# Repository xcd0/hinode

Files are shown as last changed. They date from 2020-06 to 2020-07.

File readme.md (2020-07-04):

# hinode

手配線で作る自作キーボードです。  
ケースは3Dプリンターで作りました。



  

3DモデルはFusion360で作成しています。  
元のファイルも公開してよいのですが、ちまちま修正が続いており、  
かつAutodeskのクラウド上に保存され、gitと同期が難しいため置いていません。  
あまりきれいなモデルではないですが、元のファイルが欲しい方は言ってください。  
[需要あるかわかりませんがstlファイルも置いています。](./hinode.stl)

回路図です。といっても手配線ですので目安です。  


ファームウェアはhelixのものを編集して使っています。

## キーボードレイアウト

レイヤー名をクリックすると[http://www.keyboard-layout-editor.com/](http://www.keyboard-layout-editor.com/)でふわっと作ったページに飛ぶことができます。  
レイヤーは6つあります。後ろ3つはほぼスッカスカです。  

| レイヤー番号 | 名前 | 簡単な説明 |
| :---: | :---: | --- |
| 1 | [Qwerty](http://www.keyboard-layout-editor.com/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<&_x:4%3B&=>&=6%0A%0A%0A%0AF6&=7%0A%0A%0A%0AF7&=8%0A%0A%0A%0AF8&=9%0A%0A%0A%0AF9&=0%0A%0A%0A%0AF10&=-%0A%0A%0A%0AF11&=Del%0A%0A%0A%0AF12%3B&@_c=%23f7c199%3B&=GUI&_c=%23cccccc%3B&=Tab&=Q&=W&=E&=R&=T&=(&_x:4%3B&=)&=Y&=U&=I&=O&=P&=%2F@&=Bs%3B&@_c=%23f7c199%3B&=Ins&_c=%23d18686%3B&=Sym&_c=%23cccccc%3B&=A&=S&=D&=F&=G%0A%0A%0A%0AQWERTY&=%5B%0A%0A%0A%0AEE%20RST&_x:4%3B&=%5D&=H&=J&=K&=L&=%2F%3B&=%2F:&=Ent%3B&@_c=%23f7c199%3B&=Home&=&_c=%23cccccc%3B&=Z&=X&=C&=V&=B%0A%0A%0A%0AYSTRP&=%7B%0A%0A%0A%0ARST&_x:4%3B&=%7D&=N&=M&=,&=.&=%2F%2F&=%5C&_c=%23f7c199%3B&=End%3B&@_rx:5.1&ry:9.55&y:-5.550000000000001&x:-0.5999999999999996&c=%23cccccc%3B&=英%3B&@_rx:15.1&ry:8.7&y:-4.699999999999999&x:-0.5999999999999996&c=%23f7c199%3B&=かな%3B&@_r:15&rx:5.1&y:-4.699999999999999&x:-0.5999999999999996%3B&=Ctlr%3B&@_r:30&y:-1&x:-0.5999999999999996%3B&=Shift%3B&@_r:45&y:-1&x:-0.5999999999999996%3B&=Spc%3B&@_r:60&y:-1&x:-0.5999999999999996&c=%23d18686%3B&=←%3B&@_r:-60&rx:15.1&y:-4.699999999999999&x:-0.5999999999999996%3B&=→%3B&@_r:-45&y:-1&x:-0.5999999999999996&c=%23f7c199%3B&=Bs%3B&@_r:-30&y:-1&x:-0.5999999999999996%3B&=Ent%3B&@_r:-15&y:-1&x:-0.5999999999999996%3B&=Del) | デフォルトのレイヤーです |
| 2 | [Ystrp](http://www.keyboard-layout-editor.com/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<&_x:4%3B&=>&=6%0A%0A%0A%0AF6&=7%0A%0A%0A%0AF7&=8%0A%0A%0A%0AF8&=9%0A%0A%0A%0AF9&=0%0A%0A%0A%0AF10&=-%0A%0A%0A%0AF11&=Del%0A%0A%0A%0AF12%3B&@_c=%23f7c199%3B&=GUI&_c=%23cccccc%3B&=Tab&=Q&=W&_c=%23a7a9fc%3B&=D&=F&=G&_c=%23cccccc%3B&=(&_x:4%3B&=)&=Y&_c=%23a7a9fc%3B&=S&=T&=R&_c=%23cccccc%3B&=P&=%2F@&=Bs%3B&@_c=%23f7c199%3B&=Ins&_c=%23d18686%3B&=Sym&_c=%23cccccc%3B&=A&_c=%23a7a9fc%3B&=O&=E&=U&=I%0A%0A%0A%0AQWERTY&_c=%23cccccc%3B&=%5B%0A%0A%0A%0AEE%20RST&_x:4%3B&=%5D&=H&=J&=K&=L&=%2F%3B&=%2F:&=Ent%3B&@_c=%23f7c199%3B&=Home&=&_c=%23cccccc%3B&=Z&=X&=C&=V&=B%0A%0A%0A%0AYSTRP&=%7B%0A%0A%0A%0ARST&_x:4%3B&=%7D&=N&=M&=,&=.&=%2F%2F&=%5C&_c=%23f7c199%3B&=End%3B&@_rx:5.1&ry:9.55&y:-5.550000000000001&x:-0.5999999999999996&c=%23cccccc%3B&=英%3B&@_rx:15.1&ry:8.7&y:-4.699999999999999&x:-0.5999999999999996&c=%23f7c199%3B&=かな%3B&@_r:15&rx:5.1&y:-4.699999999999999&x:-0.5999999999999996%3B&=Ctlr%3B&@_r:30&y:-1&x:-0.5999999999999996%3B&=Shift%3B&@_r:45&y:-1&x:-0.5999999999999996%3B&=Spc%3B&@_r:60&y:-1&x:-0.5999999999999996&c=%23d18686%3B&=←%3B&@_r:-60&rx:15.1&y:-4.699999999999999&x:-0.5999999999999996%3B&=→%3B&@_r:-45&y:-1&x:-0.5999999999999996&c=%23f7c199%3B&=Bs%3B&@_r:-30&y:-1&x:-0.5999999999999996%3B&=Ent%3B&@_r:-15&y:-1&x:-0.5999999999999996%3B&=Del ) | 独自キー配列のレイヤーです |
| 3 | [Symbol](http://www.keyboard-layout-editor.com/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"&='&=%60&=&_x:4%3B&=&=$&=(&=<&=%7B&=%5B&=&=Bs%3B&@_c=%23f7c199%3B&=Ins&_c=%23d18686%3B&=&_c=%23cccccc%3B&=+&=-&=*&=%2F=&=%2F:&=&_x:4%3B&=&=!&=)&=>&=%7D&=%5D&=&=Ent%3B&@_c=%23f7c199%3B&=Home&=&_c=%23cccccc%3B&=!&=%3F&=%23&=$&=%25&=&_x:4%3B&=&=&=%2F@&=%5E&=,&=&=&_c=%23f7c199%3B&=End%3B&@_rx:5.1&ry:9.55&y:-5.550000000000001&x:-0.5999999999999996&c=%23cccccc%3B&=英%3B&@_rx:15.1&ry:8.7&y:-4.699999999999999&x:-0.5999999999999996&c=%23f7c199%3B&=かな%3B&@_r:15&rx:5.1&y:-4.699999999999999&x:-0.5999999999999996%3B&=Ctlr%3B&@_r:30&y:-1&x:-0.5999999999999996%3B&=Shift%3B&@_r:45&y:-1&x:-0.5999999999999996%3B&=Spc%3B&@_r:60&y:-1&x:-0.5999999999999996&c=%23d18686%3B&=←%3B&@_r:-60&rx:15.1&y:-4.699999999999999&x:-0.5999999999999996%3B&=→%3B&@_r:-45&y:-1&x:-0.5999999999999996&c=%23f7c199%3B&=Bs%3B&@_r:-30&y:-1&x:-0.5999999999999996%3B&=Ent%3B&@_r:-15&y:-1&x:-0.5999999999999996%3B&=Del) | 記号レイヤーです |
| 4 | [Leftside](http://www.keyboard-layout-editor.com/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<br>Reset&_x:4&f:5%3B&=&=←&=↓&=↑&=→&=&=&=%3B&@_c=%23f7c199%3B&=&=&_c=%23cccccc%3B&=&=&=&=&_f:3%3B&=Ystrp&=Reset&_x:4&f:5%3B&=&=&=&=&=&=&=&_c=%23f7c199%3B&=%3B&@_rx:5.1&ry:9.55&y:-5.550000000000001&x:-0.5999999999999996&c=%23cccccc%3B&=%3B&@_rx:15.1&ry:8.7&y:-4.699999999999999&x:-0.5999999999999996&c=%23f7c199%3B&=%3B&@_r:15&rx:5.1&y:-4.699999999999999&x:-0.5999999999999996%3B&=Ctlr%3B&@_r:30&y:-1&x:-0.5999999999999996%3B&=Shift%3B&@_r:45&y:-1&x:-0.5999999999999996%3B&=Spc%3B&@_r:60&y:-1&x:-0.5999999999999996&c=%23d18686%3B&=%3B&@_r:-60&rx:15.1&y:-4.699999999999999&x:-0.5999999999999996&f:3%3B&=Adjust%3B&@_r:-45&y:-1&x:-0.5999999999999996&c=%23f7c199&f:5%3B&=Bs%3B&@_r:-30&y:-1&x:-0.5999999999999996%3B&=Ent%3B&@_r:-15&y:-1&x:-0.5999999999999996%3B&=Del) | 方向キーを置いています |
| 5 | [Rightside](http://www.keyboard-layout-editor.com/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<br>Left<br>Click&_a:5%3B&=Mouse<br>Mid<br>Click&_a:7%3B&=Mouse<br>Right<br>Click&=Mouse<br>Wheel<br>Up&_f:5%3B&=&=%3B&@_c=%23f7c199%3B&=&_c=%23d18686%3B&=&_c=%23cccccc%3B&=&=&=&=&_f:3%3B&=Qwerty&_f:1%3B&=EEPROM<br>Reset&_x:4&f:5%3B&=&_f:3%3B&=Mouse<br>←&=Mouse<br>↓&=Mouse<br>↑&=Mouse<br>→&=Mouse<br>Wheel<br>Down&_f:5%3B&=&=%3B&@_c=%23f7c199%3B&=&=&_c=%23cccccc%3B&=&=&=&=&_f:3%3B&=Ystrp&=Reset&_x:4&f:5%3B&=&=&=&=&=&=&=&_c=%23f7c199%3B&=%3B&@_rx:5.1&ry:9.55&y:-5.550000000000001&x:-0.5999999999999996&c=%23cccccc%3B&=%3B&@_rx:15.1&ry:8.7&y:-4.699999999999999&x:-0.5999999999999996&c=%23f7c199%3B&=%3B&@_r:15&rx:5.1&y:-4.699999999999999&x:-0.5999999999999996%3B&=Ctlr%3B&@_r:30&y:-1&x:-0.5999999999999996%3B&=Shift%3B&@_r:45&y:-1&x:-0.5999999999999996%3B&=Spc%3B&@_r:60&y:-1&x:-0.5999999999999996&c=%23d18686&f:3%3B&=Adjust%3B&@_r:-60&rx:15.1&y:-4.699999999999999&x:-0.5999999999999996&f:5%3B&=%3B&@_r:-45&y:-1&x:-0.5999999999999996&c=%23f7c199%3B&=Bs%3B&@_r:-30&y:-1&x:-0.5999999999999996%3B&=Ent%3B&@_r:-15&y:-1&x:-0.5999999999999996%3B&=Del) | マウスポインタの操作ができます |
| 6 | [Adjust](http://www.keyboard-layout-editor.com/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) | 何も配置していません |

## レイヤー詳細

キーボードにはレイヤーが6つ割り当てられています。  

1. [Qwerty](http://www.keyboard-layout-editor.com/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<&_x:4%3B&=>&=6%0A%0A%0A%0AF6&=7%0A%0A%0A%0AF7&=8%0A%0A%0A%0AF8&=9%0A%0A%0A%0AF9&=0%0A%0A%0A%0AF10&=-%0A%0A%0A%0AF11&=Del%0A%0A%0A%0AF12%3B&@_c=%23f7c199%3B&=GUI&_c=%23cccccc%3B&=Tab&=Q&=W&=E&=R&=T&=(&_x:4%3B&=)&=Y&=U&=I&=O&=P&=%2F@&=Bs%3B&@_c=%23f7c199%3B&=Ins&_c=%23d18686%3B&=Sym&_c=%23cccccc%3B&=A&=S&=D&=F&=G%0A%0A%0A%0AQWERTY&=%5B%0A%0A%0A%0AEE%20RST&_x:4%3B&=%5D&=H&=J&=K&=L&=%2F%3B&=%2F:&=Ent%3B&@_c=%23f7c199%3B&=Home&=&_c=%23cccccc%3B&=Z&=X&=C&=V&=B%0A%0A%0A%0AYSTRP&=%7B%0A%0A%0A%0ARST&_x:4%3B&=%7D&=N&=M&=,&=.&=%2F%2F&=%5C&_c=%23f7c199%3B&=End%3B&@_rx:5.1&ry:9.55&y:-5.550000000000001&x:-0.5999999999999996&c=%23cccccc%3B&=英%3B&@_rx:15.1&ry:8.7&y:-4.699999999999999&x:-0.5999999999999996&c=%23f7c199%3B&=かな%3B&@_r:15&rx:5.1&y:-4.699999999999999&x:-0.5999999999999996%3B&=Ctlr%3B&@_r:30&y:-1&x:-0.5999999999999996%3B&=Shift%3B&@_r:45&y:-1&x:-0.5999999999999996%3B&=Spc%3B&@_r:60&y:-1&x:-0.5999999999999996&c=%23d18686%3B&=←%3B&@_r:-60&rx:15.1&y:-4.699999999999999&x:-0.5999999999999996%3B&=→%3B&@_r:-45&y:-1&x:-0.5999999999999996&c=%23f7c199%3B&=Bs%3B&@_r:-30&y:-1&x:-0.5999999999999996%3B&=Ent%3B&@_r:-15&y:-1&x:-0.5999999999999996%3B&=Del)  
2. [Ystrp](http://www.keyboard-layout-editor.com/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<&_x:4%3B&=>&=6%0A%0A%0A%0AF6&=7%0A%0A%0A%0AF7&=8%0A%0A%0A%0AF8&=9%0A%0A%0A%0AF9&=0%0A%0A%0A%0AF10&=-%0A%0A%0A%0AF11&=Del%0A%0A%0A%0AF12%3B&@_c=%23f7c199%3B&=GUI&_c=%23dedfff%3B&=Tab&_c=%23cccccc%3B&=Q&=W&_c=%23a7a9fc%3B&=D&=F&=G&_c=%23cccccc%3B&=(&_x:4%3B&=)&=Y&_c=%23a7a9fc%3B&=S&=T&=R&_c=%23cccccc%3B&=P&=%2F@&=Bs%3B&@_c=%23f7c199%3B&=Ins&_c=%23d18686%3B&=Sym&_c=%23cccccc%3B&=A&_c=%23a7a9fc%3B&=O&=E&=U&=I%0A%0A%0A%0AQWERTY&_c=%23cccccc%3B&=%5B%0A%0A%0A%0AEE%20RST&_x:4%3B&=%5D&=H&=J&=K&=L&=%2F%3B&=%2F:&=Ent%3B&@_c=%23f7c199%3B&=Home&=&_c=%23cccccc%3B&=Z&=X&=C&=V&=B%0A%0A%0A%0AYSTRP&=%7B%0A%0A%0A%0ARST&_x:4%3B&=%7D&=N&=M&=,&=.&=%2F%2F&=%5C&_c=%23f7c199%3B&=End%3B&@_rx:5.1&ry:9.55&y:-5.550000000000001&x:-0.5999999999999996&c=%23cccccc%3B&=英%3B&@_rx:15.1&ry:8.7&y:-4.699999999999999&x:-0.5999999999999996&c=%23f7c199%3B&=かな%3B&@_r:15&rx:5.1&y:-4.699999999999999&x:-0.5999999999999996%3B&=Ctlr%3B&@_r:30&y:-1&x:-0.5999999999999996%3B&=Shift%3B&@_r:45&y:-1&x:-0.5999999999999996%3B&=Spc%3B&@_r:60&y:-1&x:-0.5999999999999996&c=%23d18686%3B&=←%3B&@_r:-60&rx:15.1&y:-4.699999999999999&x:-0.5999999999999996%3B&=→%3B&@_r:-45&y:-1&x:-0.5999999999999996&c=%23f7c199%3B&=Bs%3B&@_r:-30&y:-1&x:-0.5999999999999996%3B&=Ent%3B&@_r:-15&y:-1&x:-0.5999999999999996%3B&=Del)  
3. [Symbol](http://www.keyboard-layout-editor.com/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"&='&=%60&=&_x:4%3B&=&=$&=(&=<&=%7B&=%5B&=&=Bs%3B&@_c=%23f7c199%3B&=Ins&_c=%23d18686%3B&=&_c=%23cccccc%3B&=+&=-&=*&=%2F=&=%2F:&=&_x:4%3B&=&=!&=)&=>&=%7D&=%5D&=&=Ent%3B&@_c=%23f7c199%3B&=Home&=&_c=%23cccccc%3B&=!&=%3F&=%23&=$&=%25&=&_x:4%3B&=&=&=%2F@&=%5E&=,&=&=&_c=%23f7c199%3B&=End%3B&@_rx:5.1&ry:9.55&y:-5.550000000000001&x:-0.5999999999999996&c=%23cccccc%3B&=英%3B&@_rx:15.1&ry:8.7&y:-4.699999999999999&x:-0.5999999999999996&c=%23f7c199%3B&=かな%3B&@_r:15&rx:5.1&y:-4.699999999999999&x:-0.5999999999999996%3B&=Ctlr%3B&@_r:30&y:-1&x:-0.5999999999999996%3B&=Shift%3B&@_r:45&y:-1&x:-0.5999999999999996%3B&=Spc%3B&@_r:60&y:-1&x:-0.5999999999999996&c=%23d18686%3B&=←%3B&@_r:-60&rx:15.1&y:-4.699999999999999&x:-0.5999999999999996%3B&=→%3B&@_r:-45&y:-1&x:-0.5999999999999996&c=%23f7c199%3B&=Bs%3B&@_r:-30&y:-1&x:-0.5999999999999996%3B&=Ent%3B&@_r:-15&y:-1&x:-0.5999999999999996%3B&=Del)
4. [Leftside](http://www.keyboard-layout-editor.com/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<br>Reset&_x:4&f:5%3B&=&=←&=↓&=↑&=→&=&=&=%3B&@_c=%23f7c199%3B&=&=&_c=%23cccccc%3B&=&=&=&=&_f:3%3B&=Ystrp&=Reset&_x:4&f:5%3B&=&=&=&=&=&=&=&_c=%23f7c199%3B&=%3B&@_rx:5.1&ry:9.55&y:-5.550000000000001&x:-0.5999999999999996&c=%23cccccc%3B&=%3B&@_rx:15.1&ry:8.7&y:-4.699999999999999&x:-0.5999999999999996&c=%23f7c199%3B&=%3B&@_r:15&rx:5.1&y:-4.699999999999999&x:-0.5999999999999996%3B&=Ctlr%3B&@_r:30&y:-1&x:-0.5999999999999996%3B&=Shift%3B&@_r:45&y:-1&x:-0.5999999999999996%3B&=Spc%3B&@_r:60&y:-1&x:-0.5999999999999996&c=%23d18686%3B&=%3B&@_r:-60&rx:15.1&y:-4.699999999999999&x:-0.5999999999999996&f:3%3B&=Adjust%3B&@_r:-45&y:-1&x:-0.5999999999999996&c=%23f7c199&f:5%3B&=Bs%3B&@_r:-30&y:-1&x:-0.5999999999999996%3B&=Ent%3B&@_r:-15&y:-1&x:-0.5999999999999996%3B&=Del)
5. [Rightside](http://www.keyboard-layout-editor.com/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<br>Left<br>Click&_a:5%3B&=Mouse<br>Mid<br>Click&_a:7%3B&=Mouse<br>Right<br>Click&=Mouse<br>Wheel<br>Up&_f:5%3B&=&=%3B&@_c=%23f7c199%3B&=&_c=%23d18686%3B&=&_c=%23cccccc%3B&=&=&=&=&_f:3%3B&=Qwerty&_f:1%3B&=EEPROM<br>Reset&_x:4&f:5%3B&=&_f:3%3B&=Mouse<br>←&=Mouse<br>↓&=Mouse<br>↑&=Mouse<br>→&=Mouse<br>Wheel<br>Down&_f:5%3B&=&=%3B&@_c=%23f7c199%3B&=&=&_c=%23cccccc%3B&=&=&=&=&_f:3%3B&=Ystrp&=Reset&_x:4&f:5%3B&=&=&=&=&=&=&=&_c=%23f7c199%3B&=%3B&@_rx:5.1&ry:9.55&y:-5.550000000000001&x:-0.5999999999999996&c=%23cccccc%3B&=%3B&@_rx:15.1&ry:8.7&y:-4.699999999999999&x:-0.5999999999999996&c=%23f7c199%3B&=%3B&@_r:15&rx:5.1&y:-4.699999999999999&x:-0.5999999999999996%3B&=Ctlr%3B&@_r:30&y:-1&x:-0.5999999999999996%3B&=Shift%3B&@_r:45&y:-1&x:-0.5999999999999996%3B&=Spc%3B&@_r:60&y:-1&x:-0.5999999999999996&c=%23d18686&f:3%3B&=Adjust%3B&@_r:-60&rx:15.1&y:-4.699999999999999&x:-0.5999999999999996&f:5%3B&=%3B&@_r:-45&y:-1&x:-0.5999999999999996&c=%23f7c199%3B&=Bs%3B&@_r:-30&y:-1&x:-0.5999999999999996%3B&=Ent%3B&@_r:-15&y:-1&x:-0.5999999999999996%3B&=Del)
6. [Adjust](http://www.keyboard-layout-editor.com/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)

### 1. [Qwerty](http://www.keyboard-layout-editor.com/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<&_x:4%3B&=>&=6%0A%0A%0A%0AF6&=7%0A%0A%0A%0AF7&=8%0A%0A%0A%0AF8&=9%0A%0A%0A%0AF9&=0%0A%0A%0A%0AF10&=-%0A%0A%0A%0AF11&=Del%0A%0A%0A%0AF12%3B&@_c=%23f7c199%3B&=GUI&_c=%23cccccc%3B&=Tab&=Q&=W&=E&=R&=T&=(&_x:4%3B&=)&=Y&=U&=I&=O&=P&=%2F@&=Bs%3B&@_c=%23f7c199%3B&=Ins&_c=%23d18686%3B&=Sym&_c=%23cccccc%3B&=A&=S&=D&=F&=G%0A%0A%0A%0AQWERTY&=%5B%0A%0A%0A%0AEE%20RST&_x:4%3B&=%5D&=H&=J&=K&=L&=%2F%3B&=%2F:&=Ent%3B&@_c=%23f7c199%3B&=Home&=&_c=%23cccccc%3B&=Z&=X&=C&=V&=B%0A%0A%0A%0AYSTRP&=%7B%0A%0A%0A%0ARST&_x:4%3B&=%7D&=N&=M&=,&=.&=%2F%2F&=%5C&_c=%23f7c199%3B&=End%3B&@_rx:5.1&ry:9.55&y:-5.550000000000001&x:-0.5999999999999996&c=%23cccccc%3B&=英%3B&@_rx:15.1&ry:8.7&y:-4.699999999999999&x:-0.5999999999999996&c=%23f7c199%3B&=かな%3B&@_r:15&rx:5.1&y:-4.699999999999999&x:-0.5999999999999996%3B&=Ctlr%3B&@_r:30&y:-1&x:-0.5999999999999996%3B&=Shift%3B&@_r:45&y:-1&x:-0.5999999999999996%3B&=Spc%3B&@_r:60&y:-1&x:-0.5999999999999996&c=%23d18686%3B&=←%3B&@_r:-60&rx:15.1&y:-4.699999999999999&x:-0.5999999999999996%3B&=→%3B&@_r:-45&y:-1&x:-0.5999999999999996&c=%23f7c199%3B&=Bs%3B&@_r:-30&y:-1&x:-0.5999999999999996%3B&=Ent%3B&@_r:-15&y:-1&x:-0.5999999999999996%3B&=Del)  

一般的なQwertyです。  
デフォルトになっています。  

74キーと多少余裕があるため、`Backspace`、`Enter`、`Delete`は右手親指と右手小指に２重に配置されています。  
普段Qwertyの小指で操作しているキーですが実験的に親指に配置して使いやすいのか試しています。  
今のところそこまで使いやすいと感じているわけではないです\_(:3 」∠ )\_  

更に、`HOME`や`END`、`INSERT`を配置しているほか、1キーが何も割り当てられていません。  
`HOME`や`END`、`INSERT`は個人的に仮想端末で使い勝手が良いので置いています。  

	  /* Qwerty
	   * ,-------------------------------------------------------.  ,----------------------------------------------------------.
	   * | GUI  | ESC  |   1  |   2  |   3  |   4  |   5  |  <   |  |   >  |   6  |   7  |   8  |   9  |   0   |  -    | Delete|
	   * |------+------+------+------+------+------+------+------|  |------+------+------+------+------+-------+-------+-------|
	   * | Alt  | Tab  |   Q  |   W  |   E  |   R  |   T  |  (   |  |   )  |   Y  |   U  |   I  |   O  |   P   |  @    | BkSp  |
	   * |------+------+------+------+------+------+------+------|  |------+------+------+------+------+-------+-------+-------|
	   * |Insert|Symbol|   A  |   S  |   D  |   F  |   G  |  {   |  |   }  |   H  |   J  |   K  |   L  |   ;   |  :    | Enter |
	   * |------+------+------+------+------+------+------+------|  |------+------+------+------+------+-------+-------+-------|
	   * | HOME |      |   Z  |   X  |   C  |   V  |   B  |  [   |  |   ]  |   N  |   M  |   ,  |   .  |   /   |  \    |  END  |
	   * `--------------------+------+------+------+------+------|  |------+------+------+------+------+-----------------------'
	   *                      | EISU | Ctrl |Space |Shift | LEFT |  |RIGHT | BkSp |Enter |Delete| KANA |
	   *                      `----------------------------------'  `----------------------------------'
	   */

### 2. [Ystrp](http://www.keyboard-layout-editor.com/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<&_x:4%3B&=>&=6%0A%0A%0A%0AF6&=7%0A%0A%0A%0AF7&=8%0A%0A%0A%0AF8&=9%0A%0A%0A%0AF9&=0%0A%0A%0A%0AF10&=-%0A%0A%0A%0AF11&=Del%0A%0A%0A%0AF12%3B&@_c=%23f7c199%3B&=GUI&_c=%23cccccc%3B&=Tab&=Q&=W&_c=%23a7a9fc%3B&=D&=F&=G&_c=%23cccccc%3B&=(&_x:4%3B&=)&=Y&_c=%23a7a9fc%3B&=S&=T&=R&_c=%23cccccc%3B&=P&=%2F@&=Bs%3B&@_c=%23f7c199%3B&=Ins&_c=%23d18686%3B&=Sym&_c=%23cccccc%3B&=A&_c=%23a7a9fc%3B&=O&=E&=U&=I%0A%0A%0A%0AQWERTY&_c=%23cccccc%3B&=%5B%0A%0A%0A%0AEE%20RST&_x:4%3B&=%5D&=H&=J&=K&=L&=%2F%3B&=%2F:&=Ent%3B&@_c=%23f7c199%3B&=Home&=&_c=%23cccccc%3B&=Z&=X&=C&=V&=B%0A%0A%0A%0AYSTRP&=%7B%0A%0A%0A%0ARST&_x:4%3B&=%7D&=N&=M&=,&=.&=%2F%2F&=%5C&_c=%23f7c199%3B&=End%3B&@_rx:5.1&ry:9.55&y:-5.550000000000001&x:-0.5999999999999996&c=%23cccccc%3B&=英%3B&@_rx:15.1&ry:8.7&y:-4.699999999999999&x:-0.5999999999999996&c=%23f7c199%3B&=かな%3B&@_r:15&rx:5.1&y:-4.699999999999999&x:-0.5999999999999996%3B&=Ctlr%3B&@_r:30&y:-1&x:-0.5999999999999996%3B&=Shift%3B&@_r:45&y:-1&x:-0.5999999999999996%3B&=Spc%3B&@_r:60&y:-1&x:-0.5999999999999996&c=%23d18686%3B&=←%3B&@_r:-60&rx:15.1&y:-4.699999999999999&x:-0.5999999999999996%3B&=→%3B&@_r:-45&y:-1&x:-0.5999999999999996&c=%23f7c199%3B&=Bs%3B&@_r:-30&y:-1&x:-0.5999999999999996%3B&=Ent%3B&@_r:-15&y:-1&x:-0.5999999999999996%3B&=Del )  

QwertyからDvorakのように左手ホームポジションに母音を集めた独自キーマップです。  
日本語の交互打鍵を意識しています。  
Qwertyからできるだけ変更せずに使えるよう最低限の変更にしています。(10キーの変更)  

ホームポジションに母音を置くために元々Qwertyにある`SDFG`をどかし、  
母音をDvorakと同じように並べ、  
左手の`E`と右手の`UIO`のあったところに、どかした`SDFG`を置きました。  
すると`T`は交互打鍵の都合上右手に欲しくなったため、  
`G`を左手(Qwertyの`G`の一つ上)に戻し、`T`を右手に移動させました。  

	  /* Ystrp
	   * ,-------------------------------------------------------.  ,----------------------------------------------------------.
	   * | Alt  | ESC  |   1  |   2  |   3  |   4  |   5  |  <   |  |   >  |   6  |   7  |   8  |   9  |   0   |  -    | Delete|
	   * |------+------+------+------+------+------+------+------|  |------+------+------+------+------+-------+-------+-------|
	   * | GUI  | Tab  |   Q  |   W  |  "D" |  "F" |  "G" |  (   |  |   )  |   Y  |  "S" |  "T" |  "R" |   P   |  @    | BkSp  |
	   * |------+------+------+------+------+------+------+------|  |------+------+------+------+------+-------+-------+-------|
	   * |Insert|Symbol|   A  |  "O" |  "E" |  "U" |  "I" |  {   |  |   }  |   H  |   J  |   K  |   L  |   ;   |  :    | Enter |
	   * |------+------+------+------+------+------+------+------|  |------+------+------+------+------+-------+-------+-------|
	   * | HOME |      |   Z  |   X  |   C  |   V  |   B  |  [   |  |   ]  |   N  |   M  |   ,  |   .  |   /   |  \    |  END  |
	   * `--------------------+------+------+------+------+------|  |------+------+------+------+------+-----------------------'
	   *                      | EISU | Ctrl |Space |Shift | LEFT |  |RIGHT | BkSp |Enter |Delete| KANA |
	   *                      `----------------------------------'  `----------------------------------'
	   */

`Qwerty`と`Ystrp`は、 `Leftside` または `Rightside` の `Qwerty` と `Ystrp` から切り替えることができます。

### 3. [Symbol](http://www.keyboard-layout-editor.com/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"&='&=%60&=&_x:4%3B&=&=$&=(&=<&=%7B&=%5B&=&=Bs%3B&@_c=%23f7c199%3B&=Ins&_c=%23d18686%3B&=&_c=%23cccccc%3B&=+&=-&=*&=%2F=&=%2F:&=&_x:4%3B&=&=!&=)&=>&=%7D&=%5D&=&=Ent%3B&@_c=%23f7c199%3B&=Home&=&_c=%23cccccc%3B&=!&=%3F&=%23&=$&=%25&=&_x:4%3B&=&=&=%2F@&=%5E&=,&=&=&_c=%23f7c199%3B&=End%3B&@_rx:5.1&ry:9.55&y:-5.550000000000001&x:-0.5999999999999996&c=%23cccccc%3B&=英%3B&@_rx:15.1&ry:8.7&y:-4.699999999999999&x:-0.5999999999999996&c=%23f7c199%3B&=かな%3B&@_r:15&rx:5.1&y:-4.699999999999999&x:-0.5999999999999996%3B&=Ctlr%3B&@_r:30&y:-1&x:-0.5999999999999996%3B&=Shift%3B&@_r:45&y:-1&x:-0.5999999999999996%3B&=Spc%3B&@_r:60&y:-1&x:-0.5999999999999996&c=%23d18686%3B&=←%3B&@_r:-60&rx:15.1&y:-4.699999999999999&x:-0.5999999999999996%3B&=→%3B&@_r:-45&y:-1&x:-0.5999999999999996&c=%23f7c199%3B&=Bs%3B&@_r:-30&y:-1&x:-0.5999999999999996%3B&=Ent%3B&@_r:-15&y:-1&x:-0.5999999999999996%3B&=Del)

記号レイヤーです。  
`Qwerty`と`Ystrp`の左手小指のキーから遷移できます。  
特にこだわりなく並べました。  
おそらく今後一番変更があるレイヤーだと思います。

	  /* Symbol
	   * ,-------------------------------------------------------.  ,--------------------------------------------------------.
	   * | Alt  | ESC  |  1   |  2   |  3   |  4   |  5   |      |  |      |  6   |  7   |  8   |  9   |  0   |      | Delete|
	   * |------+------+------+------+------+------+------+------|  |------+------+------+------+------+------+------+-------|
	   * | GUI  | TAB  |      |  _   |  "   |  '   |  `   |      |  |      |  &   |  (   |  <   |  {   |  [   |      | BkSp  |
	   * |------+------+------+------+------+------+------+------|  |------+------+------+------+------+------+------+-------|
	   * |Insert|      |  +   |  -   |  *   |  =   |  :   |      |  |      |  |   |  )   |  >   |  }   |  ]   |      | Enter |
	   * |------+------+------+------+------+------+------+------|  |------+------+------+------+------+------+------+-------|
	   * | HOME |      |  !   |  ?   |  #   |  $   |  %   |      |  |      |      |  @   |  ^   |  ,   |      |      |  END  |
	   * `--------------------+------+------+------+------+------|  |------+------+------+------+------+---------------------'
	   *                      | EISU | Ctrl |Space |Shift | LEFT |  |RIGHT | BkSp |Enter |Delete| KANA |
	   *                      `----------------------------------'  `----------------------------------'
	   */

### 4. [Leftside](http://www.keyboard-layout-editor.com/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<br>Reset&_x:4&f:5%3B&=&=←&=↓&=↑&=→&=&=&=%3B&@_c=%23f7c199%3B&=&=&_c=%23cccccc%3B&=&=&=&=&_f:3%3B&=Ystrp&=Reset&_x:4&f:5%3B&=&=&=&=&=&=&=&_c=%23f7c199%3B&=%3B&@_rx:5.1&ry:9.55&y:-5.550000000000001&x:-0.5999999999999996&c=%23cccccc%3B&=%3B&@_rx:15.1&ry:8.7&y:-4.699999999999999&x:-0.5999999999999996&c=%23f7c199%3B&=%3B&@_r:15&rx:5.1&y:-4.699999999999999&x:-0.5999999999999996%3B&=Ctlr%3B&@_r:30&y:-1&x:-0.5999999999999996%3B&=Shift%3B&@_r:45&y:-1&x:-0.5999999999999996%3B&=Spc%3B&@_r:60&y:-1&x:-0.5999999999999996&c=%23d18686%3B&=%3B&@_r:-60&rx:15.1&y:-4.699999999999999&x:-0.5999999999999996&f:3%3B&=Adjust%3B&@_r:-45&y:-1&x:-0.5999999999999996&c=%23f7c199&f:5%3B&=Bs%3B&@_r:-30&y:-1&x:-0.5999999999999996%3B&=Ent%3B&@_r:-15&y:-1&x:-0.5999999999999996%3B&=Del)

方向キーのレイヤーです。ファンクションキーも配置しています。  
`Leftside`へは`Qwerty`と`Ystrp`の左手親指のキーから遷移できます。  
`Qwerty`と`Ystrp`へ切り替えるキーが配置されています。  

	  /* LEFT
	   * ,-------------------------------------------------------.  ,---------------------------------------------------------.
	   * |      |      |  F1  |  F2  |  F3  |  F4  |  F5  |      |  |      |  F6  |  F7  |  F8  |  F9  |  F10  |  F11  |  F12  |
	   * |------+------+------+------+------+------+------+------|  |------+------+------+------+------+-------+-------+-------|
	   * |      |      |      |      |      |      |      |      |  |      |      |      |      |      |       |       |       |
	   * |------+------+------+------+------+------+------+------|  |------+------+------+------+------+-------+-------+-------|
	   * |      |      |      |      |      |      |Qwerty|EEPROM|  |      | Left | Down |  Up  |Right |       |       |       |
	   * |------+------+------+------+------+------+------+------|  |------+------+------+------+------+-------+-------+-------|
	   * |      |      |      |      |      |      |Ystrp |Reset |  |      |      |      |      |      |       |       |       |
	   * `--------------------+------+------+------+------+------|  |------+------+------+------+------+-----------------------'
	   *                      |      | Ctrl |Space |Shift |      |  |Adjust| BkSp |Enter |Delete|      |
	   *                      `----------------------------------'  `----------------------------------'
	   */

### 5. [Rightside](http://www.keyboard-layout-editor.com/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<br>Left<br>Click&_a:5%3B&=Mouse<br>Mid<br>Click&_a:7%3B&=Mouse<br>Right<br>Click&=Mouse<br>Wheel<br>Up&_f:5%3B&=&=%3B&@_c=%23f7c199%3B&=&_c=%23d18686%3B&=&_c=%23cccccc%3B&=&=&=&=&_f:3%3B&=Qwerty&_f:1%3B&=EEPROM<br>Reset&_x:4&f:5%3B&=&_f:3%3B&=Mouse<br>←&=Mouse<br>↓&=Mouse<br>↑&=Mouse<br>→&=Mouse<br>Wheel<br>Down&_f:5%3B&=&=%3B&@_c=%23f7c199%3B&=&=&_c=%23cccccc%3B&=&=&=&=&_f:3%3B&=Ystrp&=Reset&_x:4&f:5%3B&=&=&=&=&=&=&=&_c=%23f7c199%3B&=%3B&@_rx:5.1&ry:9.55&y:-5.550000000000001&x:-0.5999999999999996&c=%23cccccc%3B&=%3B&@_rx:15.1&ry:8.7&y:-4.699999999999999&x:-0.5999999999999996&c=%23f7c199%3B&=%3B&@_r:15&rx:5.1&y:-4.699999999999999&x:-0.5999999999999996%3B&=Ctlr%3B&@_r:30&y:-1&x:-0.5999999999999996%3B&=Shift%3B&@_r:45&y:-1&x:-0.5999999999999996%3B&=Spc%3B&@_r:60&y:-1&x:-0.5999999999999996&c=%23d18686&f:3%3B&=Adjust%3B&@_r:-60&rx:15.1&y:-4.699999999999999&x:-0.5999999999999996&f:5%3B&=%3B&@_r:-45&y:-1&x:-0.5999999999999996&c=%23f7c199%3B&=Bs%3B&@_r:-30&y:-1&x:-0.5999999999999996%3B&=Ent%3B&@_r:-15&y:-1&x:-0.5999999999999996%3B&=Del)

マウスポインタのレイヤーです。ファンクションキーも配置しています。  
`Rightside`へは`Qwerty`と`Ystrp`の右手親指のキーから遷移できます。  
`Qwerty`と`Ystrp`へ切り替えるキーが配置されています。  

	  /* Right
	   * ,-------------------------------------------------------.  ,---------------------------------------------------------.
	   * |      |      |  F1  |  F2  |  F3  |  F4  |  F5  |      |  |      |  F6  |  F7  |  F8  |  F9  |  F10  |  F11  |  F12  |
	   * |------+------+------+------+------+------+------+------|  |------+------+------+------+------+-------+-------+-------|
	   * |      |      |      |      |      |      |      |      |  |      |      | M.lc | M.mc | M.rc | wh.u  |       |       |
	   * |------+------+------+------+------+------+------+------|  |------+------+------+------+------+-------+-------+-------|
	   * |      |      |      |      |      |      |Qwerty|EEPROM|  |      | M.l  | M.d  | M.u  | M.r  | wh.d  |       |       |
	   * |------+------+------+------+------+------+------+------|  |------+------+------+------+------+-------+-------+-------|
	   * |      |      |      |      |      |      |Ystrp |Reset |  |      |      |      |      |      |       |       |       |
	   * `--------------------+------+------+------+------+------|  |------+------+------+------+------+-----------------------'
	   *                      |      | Ctrl |Space |Shift |Adjust|  |      | BkSp |Enter |Delete|      |
	   *                      `----------------------------------'  `----------------------------------'
	   */

### 6. [Adjust](http://www.keyboard-layout-editor.com/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)

LeftとRightを同時押しするとこのレイヤーになります。  
特に何も配置していません。いい使い道があれば使います。

	  /* Adjust
	   * LeftとRightを同時押しするとこのレイヤーになります。特に何も配置していません。
	   * ,-------------------------------------------------------.  ,----------------------------------------------------------.
	   * |      |      |      |      |      |      |      |      |  |      |      |      |      |      |       |       |       |
	   * |------+------+------+------+------+------+------+------|  |------+------+------+------+------+-------+-------+-------|
	   * |      |      |      |      |      |      |      |      |  |      |      |      |      |      |       |       |       |
	   * |------+------+------+------+------+------+------+------|  |------+------+------+------+------+-------+-------+-------|
	   * |      |      |      |      |      |      |      |      |  |      |      |      |      |      |       |       |       |
	   * |------+------+------+------+------+------+------+------|  |------+------+------+------+------+-------+-------+-------|
	   * |      |      |      |      |      |      |      |      |  |      |      |      |      |      |       |       |       |
	   * `--------------------+------+------+------+------+------|  |------+------+------+------+------+-----------------------'
	   *                      |      |      |      |      |      |  |      |      |      |      |      |
	   *                      `----------------------------------'  `----------------------------------'
	   */

## ファームウェアのビルド方法

1. [https://github.com/qmk/qmk_firmware.git](https://github.com/qmk/qmk_firmware.git)  
をクローンしたディレクトリと同じ場所にこのリポジトリをクローンする。

2. `./build_hinode.sh` を実行する。

```
./
├── qmk_firmware          クローンしてきたqmk_firmware
│  └── keyboards         ここにhinodeがコピーされる
└── hinode
	├── hinode            ファームウェア本体
	└── readme.md         このreadme.md
```

3. このディレクトリにビルドしたファームウェアが保存される。

## 注意

キーボードの`KANA`と`EISU`は`変換`と`無変換`を割り当てています。  
Windows10 2004でのIMEの設定で`変換`と`無変換`をIMEのON/OFFに割り当てて使っています。

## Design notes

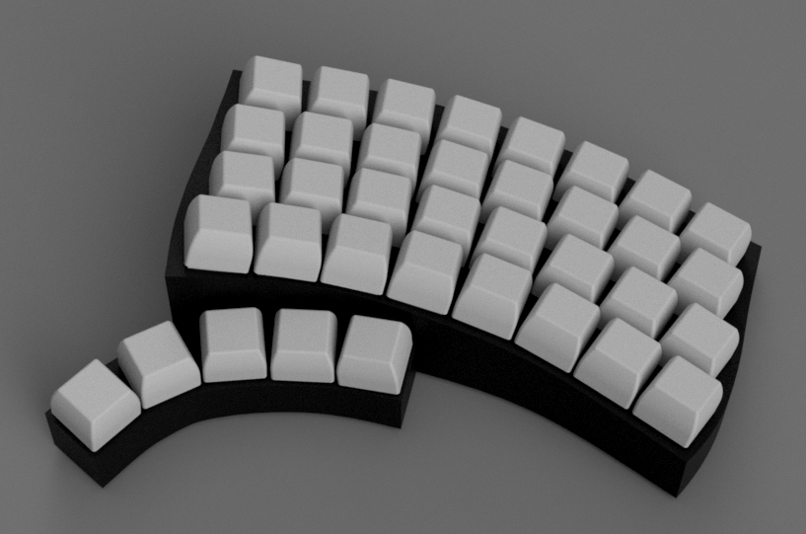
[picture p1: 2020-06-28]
hinode.png

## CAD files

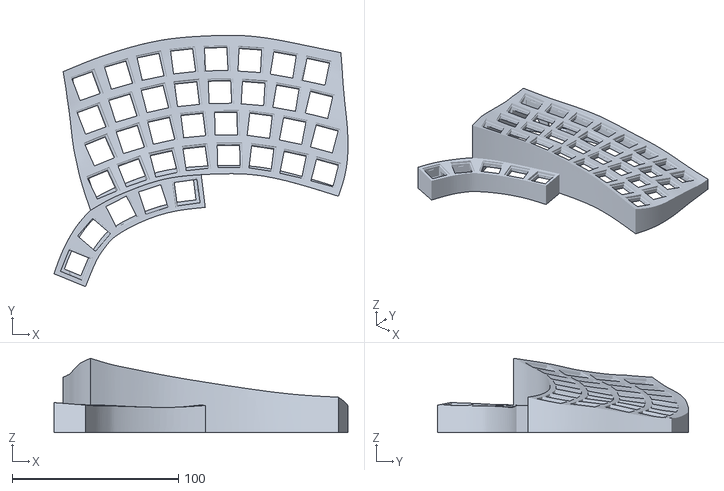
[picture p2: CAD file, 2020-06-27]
hinode.stl
176.8 x 151.2 x 44.8

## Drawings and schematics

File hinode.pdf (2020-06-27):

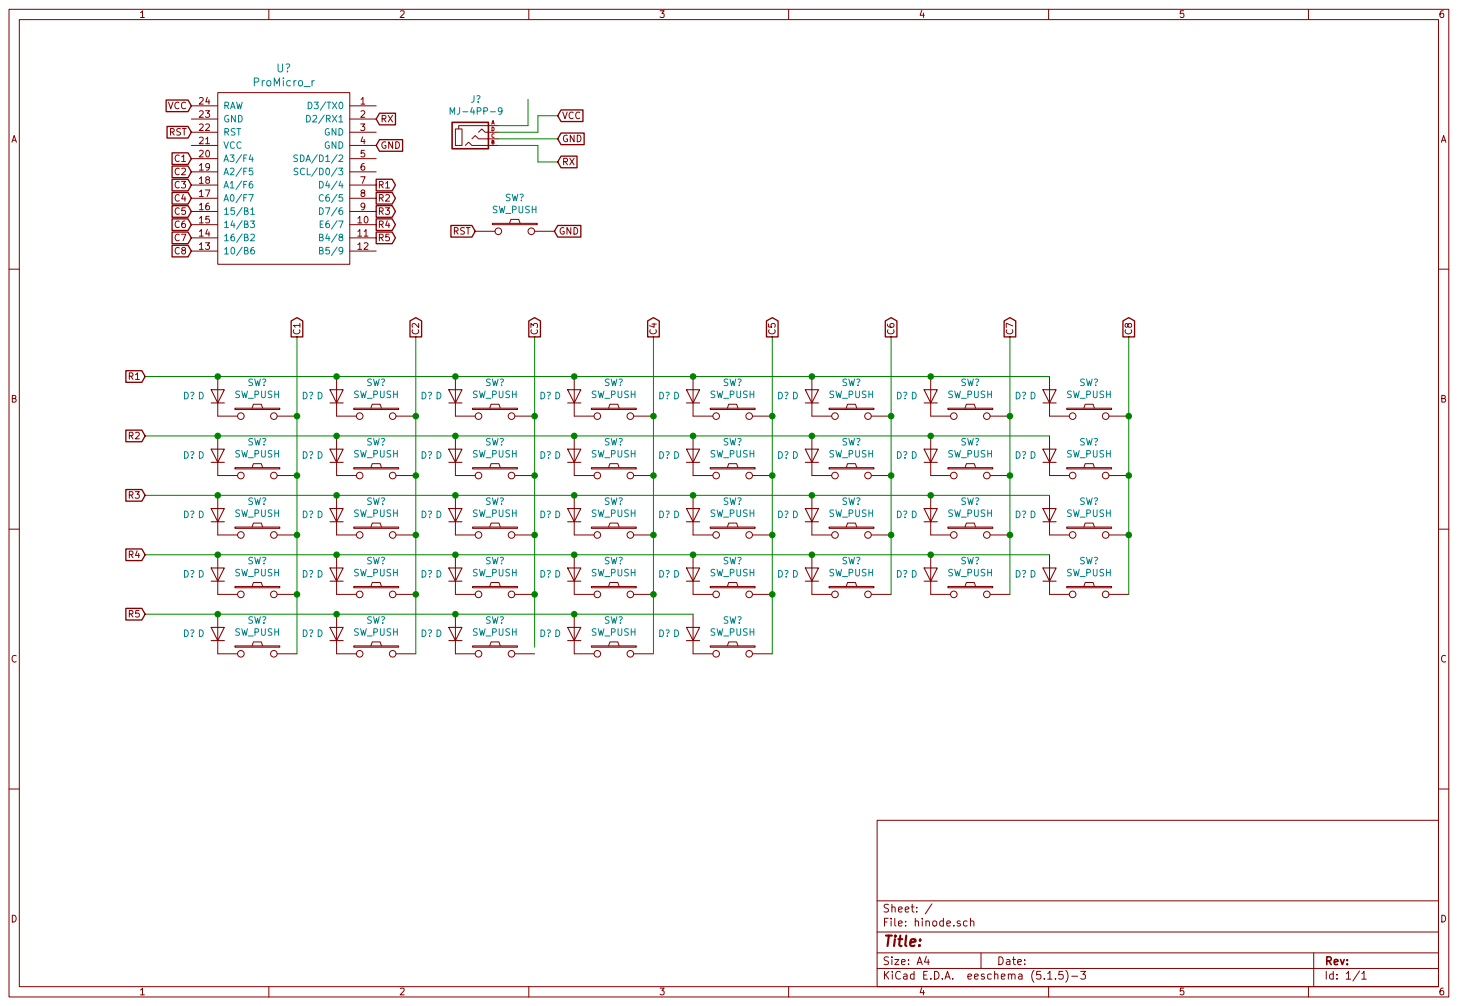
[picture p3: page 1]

Id: 1/1 Title: File: hinode.sch Sheet: / D? D

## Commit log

2020-06-27 QMK firmwareのhelixをコピーしてきた
2020-06-27 add readme.md
    [hinode.sch, hinode.stl]
2020-06-27 使わないキーマップを削除
2020-06-27 defaultのキーマップを更新
2020-06-27 helixのファームウェアをhinode用に改造
2020-06-27 左手の並びがおかしかったので修正
